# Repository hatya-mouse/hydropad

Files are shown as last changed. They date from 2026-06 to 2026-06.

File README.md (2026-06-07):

# HydroPad

HydroPad is a macropad with some holes for the water to go through, designed for people with palmar hyperhidrosis.

## Gallery

HydroPad
*Screenshot of the assembled model*

Schematic
*Schematic of HydroPad*

PCB
*PCB layout of HydroPad*

Top Plate
*Top plate design*

Bottom Case
*Bottom case design*

## Required Components

- 1x PCB
- 1x Top Plate
- 1x Bottom Case

- 1x Seeed XIAO RP2040
- 6x through-hole 1N4148 Diodes
- 5x MX-Style switches
- 1x EC11 Rotary encoders
- 1x 0.91 inch OLED display
- 5x blank DSA keycaps
- 4x M3x5mx4mm heatset inserts
(I'll use my own screws instead of M3x16mm screws included in the kit)

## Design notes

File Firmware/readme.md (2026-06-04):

# HydroPad

HydroPad

HydroPad is a keyboard with 5 keys and 1 rotary encoder. The keyboard is designed for the people with palmar hyperhidrosis.

* Keyboard Maintainer: [Shuntaro Kasatani](https://github.com/Hatya-mouse)
* Hardware Supported: *The PCBs, controllers supported*
* Hardware Availability: *Links to where you can find this hardware*

See the [build environment setup](https://docs.qmk.fm/#/getting_started_build_tools) and the [make instructions](https://docs.qmk.fm/#/getting_started_make_guide) for more information. Brand new to QMK? Start with our [Complete Newbs Guide](https://docs.qmk.fm/#/newbs).

## Bootloader

Enter the bootloader in 3 ways:

* **Bootmagic reset**: Hold down the key at (0,0) in the matrix (usually the top left key or Escape) and plug in the keyboard
* **Physical reset button**: Briefly press the button on the back of the PCB - some may have pads you must short instead
* **Keycode in layout**: Press the key mapped to `QK_BOOT` if it is available

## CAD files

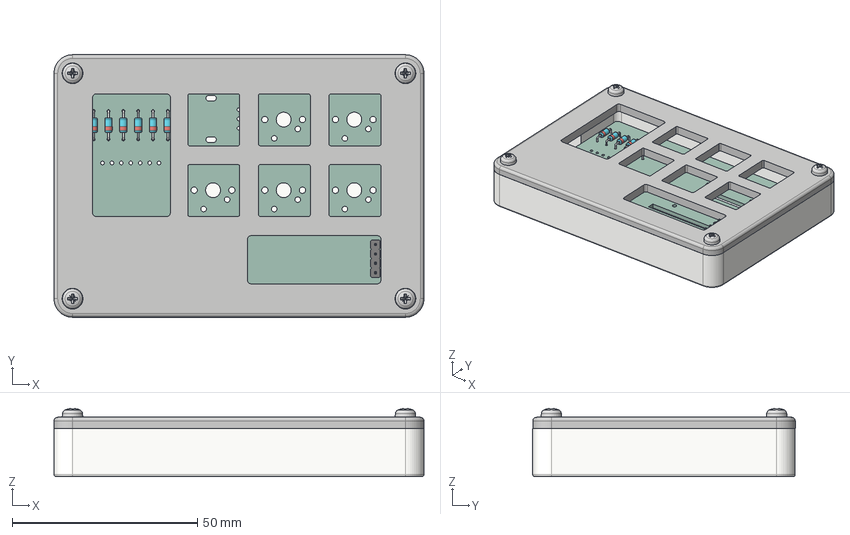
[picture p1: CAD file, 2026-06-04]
CAD/assembled-model.STEP
99.8 x 70.8 x 18.4 mm
PHS JIS B 1111 - M3 x 16 - Z Steel 4.6 Plain x 4
D_DO-35_SOD27_P7.62mm_Horizontal_6 x 6
PinHeader_1x04_P254mm_Vertical
hydropad_PCB

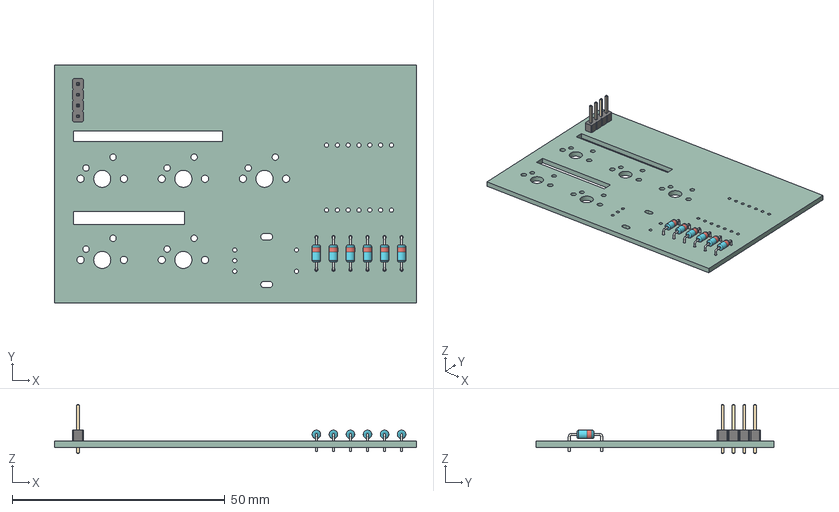
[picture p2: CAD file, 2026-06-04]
CAD/hydropad_pcb.STEP
85.0 x 56.0 x 11.5 mm
D_DO-35_SOD27_P7.62mm_Horizontal x 6
PinHeader_1x04_P254mm_Vertical
hydropad_PCB

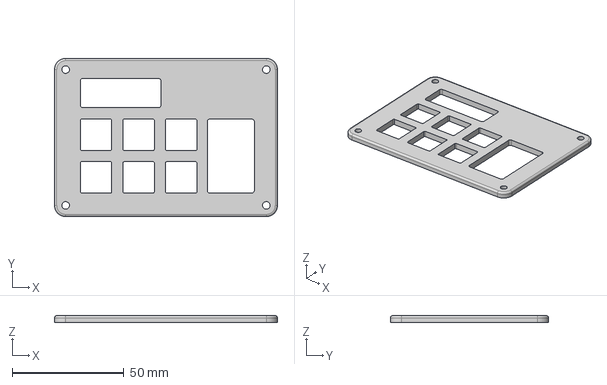
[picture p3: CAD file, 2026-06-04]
production/Top.STEP
99.8 x 70.8 x 3.00 mm

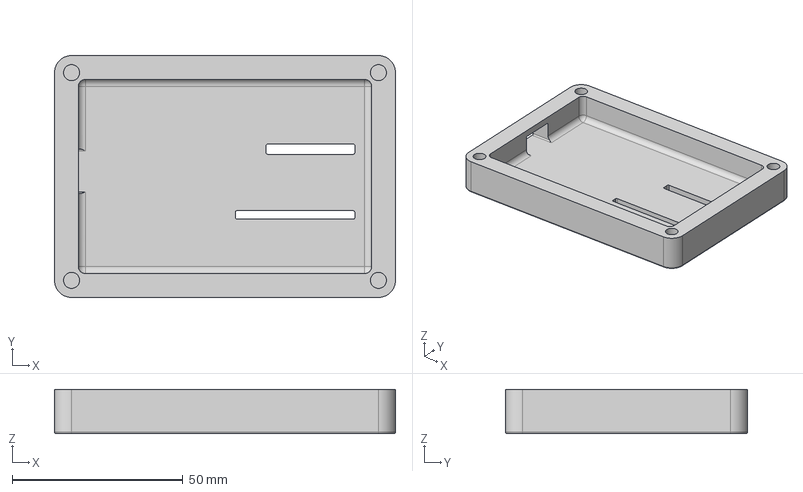
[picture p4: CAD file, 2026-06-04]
production/Bottom.STEP
99.8 x 70.8 x 13.0 mm

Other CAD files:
production/Bottom.stl
production/Top.stl

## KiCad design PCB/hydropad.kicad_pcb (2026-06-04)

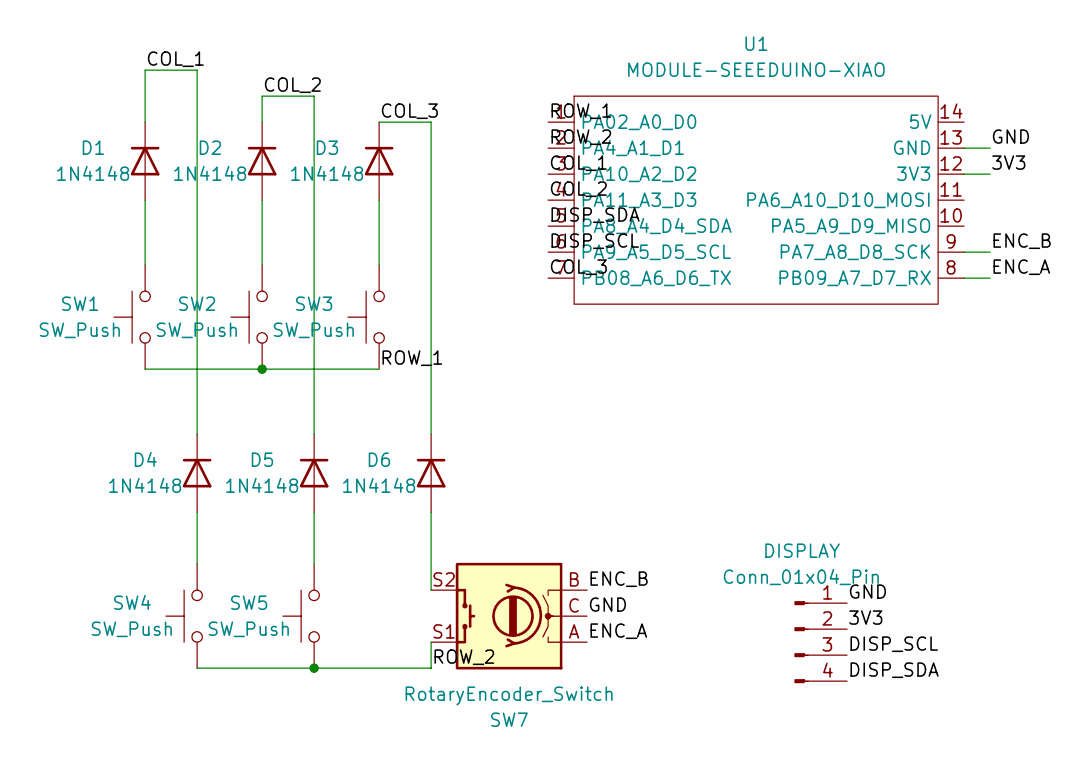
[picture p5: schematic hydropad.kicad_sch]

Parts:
D1, D2, D3, D4, D5, D6: 1N4148; D_DO-35_SOD27_P7.62mm_Horizontal
DISPLAY: Conn_01x04_Pin; PinHeader_1x04_P2.54mm_Vertical
SW1, SW2, SW3, SW4, SW5: SW_Push; SW_Cherry_MX_1.00u_PCB
SW7: RotaryEncoder_Switch; RotaryEncoder_Alps_EC11E-Switch_Vertical_H20mm
U1: MODULE-SEEEDUINO-XIAO; XIAO-Generic-Hybrid-14P-2.54-21X17.8MM

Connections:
/3V3: DISPLAY.2, U1.12 (3V3)
/COL_1: D1.1 (K), D4.1 (K), U1.3 (PA10_A2_D2)
/COL_2: D2.1 (K), D5.1 (K), U1.4 (PA11_A3_D3)
/COL_3: D3.1 (K), D6.1 (K), U1.7 (PB08_A6_D6_TX)
/DISP_SCL: DISPLAY.3, U1.6 (PA9_A5_D5_SCL)
/DISP_SDA: DISPLAY.4, U1.5 (PA8_A4_D4_SDA)
/ENC_A: SW7.A, U1.8 (PB09_A7_D7_RX); also elsewhere on the board
/ENC_B: SW7.B, U1.9 (PA7_A8_D8_SCK); also elsewhere on the board
/GND: DISPLAY.1, SW7.C, U1.13 (GND); also elsewhere on the board
/ROW_1: SW1.1, SW2.1, SW3.1, U1.1 (PA02_A0_D0)
/ROW_2: SW4.1, SW5.1, SW7.S1, U1.2 (PA4_A1_D1); also elsewhere on the board
unnamed: D1.2 (A), SW1.2
unnamed: D2.2 (A), SW2.2
unnamed: D3.2 (A), SW3.2
unnamed: D4.2 (A), SW4.2
unnamed: D5.2 (A), SW5.2
unnamed 16: D6.2 (A), SW7.S2; also elsewhere on the board

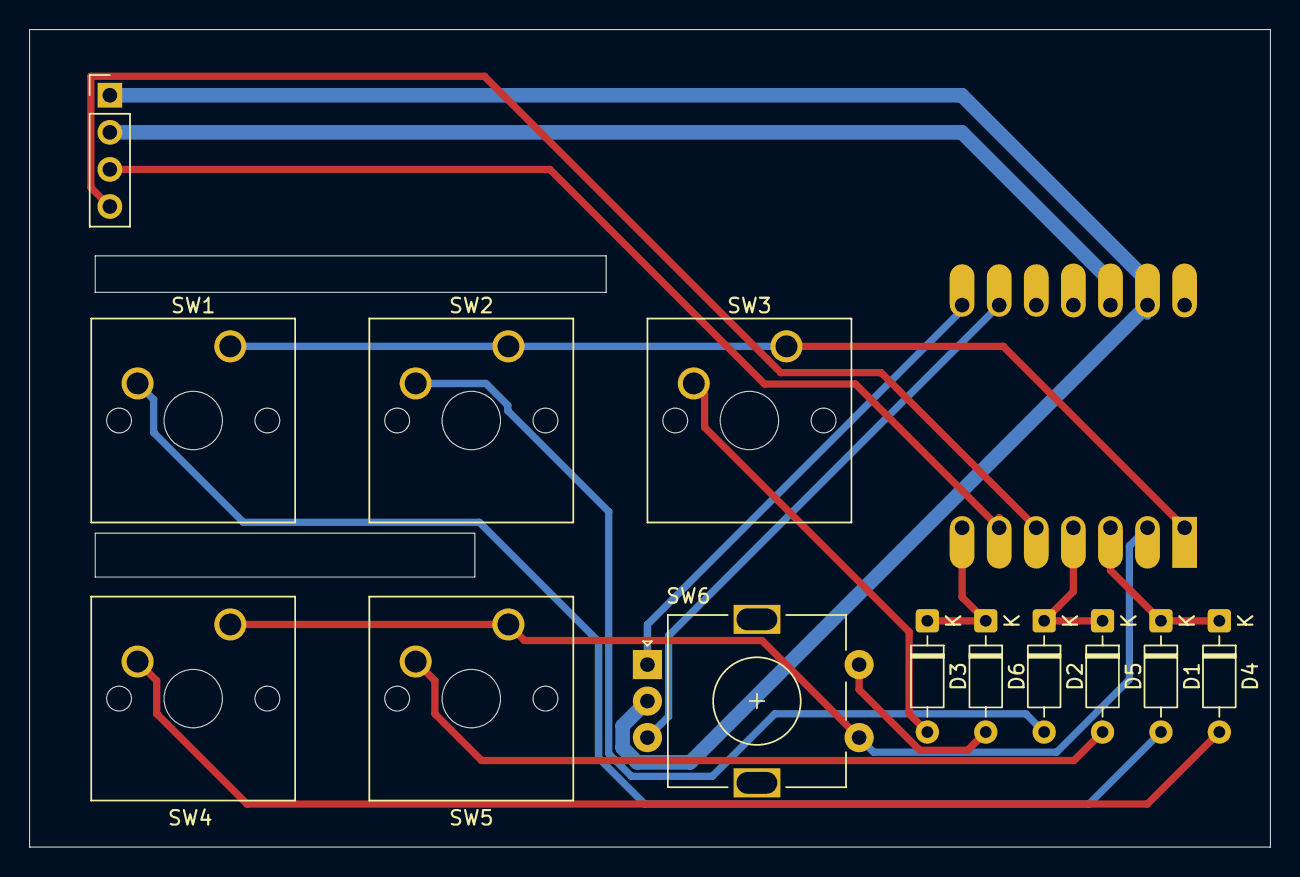
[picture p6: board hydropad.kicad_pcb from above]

Board: 2 copper layers, 85.0 x 56.0 mm, 14 parts (1 on the bottom side), 17 nets.

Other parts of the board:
SW6: RotaryEncoder_Switch; RotaryEncoder_Alps_EC11E-Switch_Vertical_H20mm

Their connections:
/ENC_A: SW6.A; also elsewhere on the board
/ENC_B: SW6.B; also elsewhere on the board
/GND: SW6.C; also elsewhere on the board
/ROW_2: SW6.S1; also elsewhere on the board
unnamed 16: SW6.S2; also elsewhere on the board

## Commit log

2026-06-04 chore: initial commit
    [hydropad-B_Cu.gbr, hydropad-B_Mask.gbr, hydropad-B_Paste.gbr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]
2026-06-04 chore: add PCB/.history to gitignore
2026-06-04 feat: add simple encoder and oled implementation
2026-06-04 chore: add PCB/~hydropad* to gitignore
2026-06-04 Add some CAD data
    [Bottom.STEP, Top.STEP, assembled-model.STEP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]
2026-06-04 docs: add some images to README
    [assembled-model.STEP, hydropad_assembly.step, hydropad_pcb.step]
2026-06-04 fix: fix firmware syntax and compile the binary
    [assembled-model.step]
2026-06-04 docs: update image of assembled model in README.md
2026-06-04 fix: rename step files to meet the requirements
    [assembled-model.STEP, hydropad_pcb.STEP]
2026-08-16 feat: add STL file
    [Bottom.stl, Top.stl]
